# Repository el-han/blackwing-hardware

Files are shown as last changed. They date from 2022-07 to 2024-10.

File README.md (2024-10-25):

# Blackwing keyboard

The Blackwing keyboard is a vertically staggered split keyboard inspired by the [Mitosis keyboard](https://github.com/reversebias/mitosis).

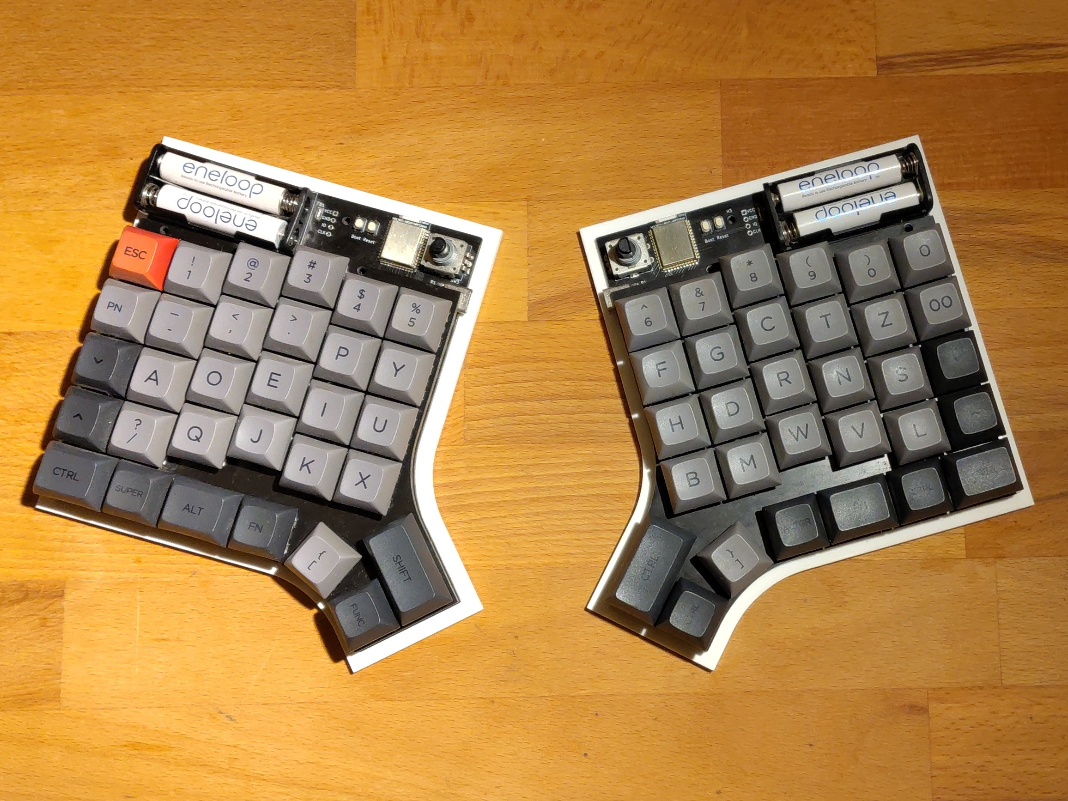
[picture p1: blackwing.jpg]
Don't mind the keycap labels


## Features

- QMK firmware
- Cherry MX switches
- nRF52840 module
- NKRO as each switch is wired to its own GPIO
- Nordic's proprietary low power radio protocol
- Uses the receiver from the [Mitosis keyboard](https://github.com/reversebias/mitosis)
- Runs months to years on battery as it stays in deep sleep until a button is pressed or released
- PCB plate for plate mounted switches

## Todo

- Merge firmware into QMK project
- Use nRF 52840 dongle as receiver
- Build a ZMK based firmware
- Add Bluetooth support

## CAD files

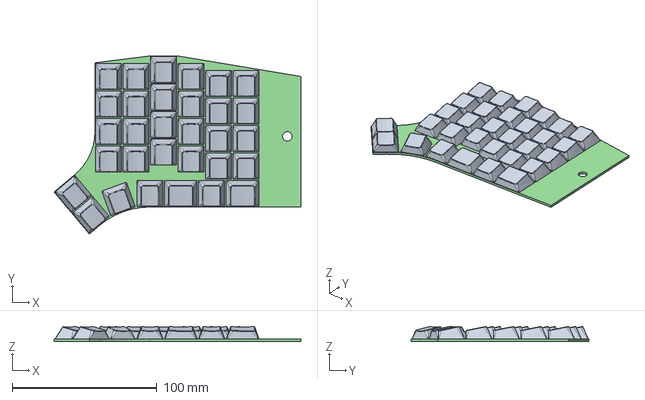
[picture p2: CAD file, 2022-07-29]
plate/plate.step
170.8 x 123.2 x 10.3 mm

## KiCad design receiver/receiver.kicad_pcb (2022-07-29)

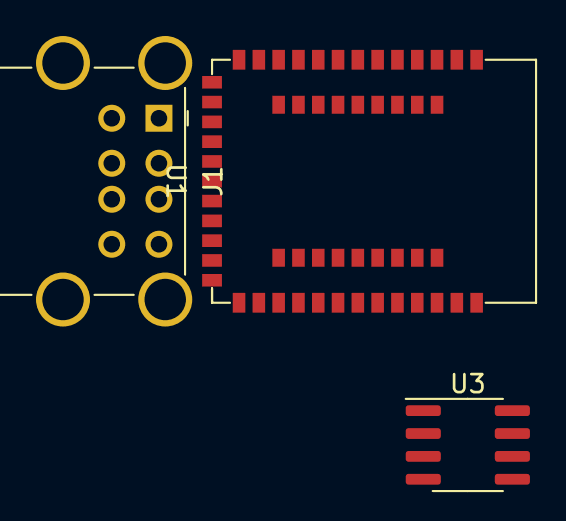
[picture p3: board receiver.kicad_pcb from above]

Board: 2 copper layers, 4 parts (1 on the bottom side), 4 nets, no tracks yet.

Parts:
J1: USB_A; USB_A_Wuerth_61400826021_Horizontal_Stacked
U1: HOLYIOT-18010-NRF52840
U2: ATmega32U4-A; TQFP-44_10x10mm_P0.8mm
U3: AMS1117CS-3.3; SOIC-8_3.9x4.9mm_P1.27mm

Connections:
unnamed: U2.14 (VCC), U2.34 (VCC)
unnamed: U2.15 (GND), U2.23 (GND), U2.35 (GND), U2.43 (GND)
unnamed: U2.24 (AVCC), U2.44 (AVCC)
unnamed: U3.2 (VO), U3.3 (VO), U3.6 (VO), U3.7 (VO)

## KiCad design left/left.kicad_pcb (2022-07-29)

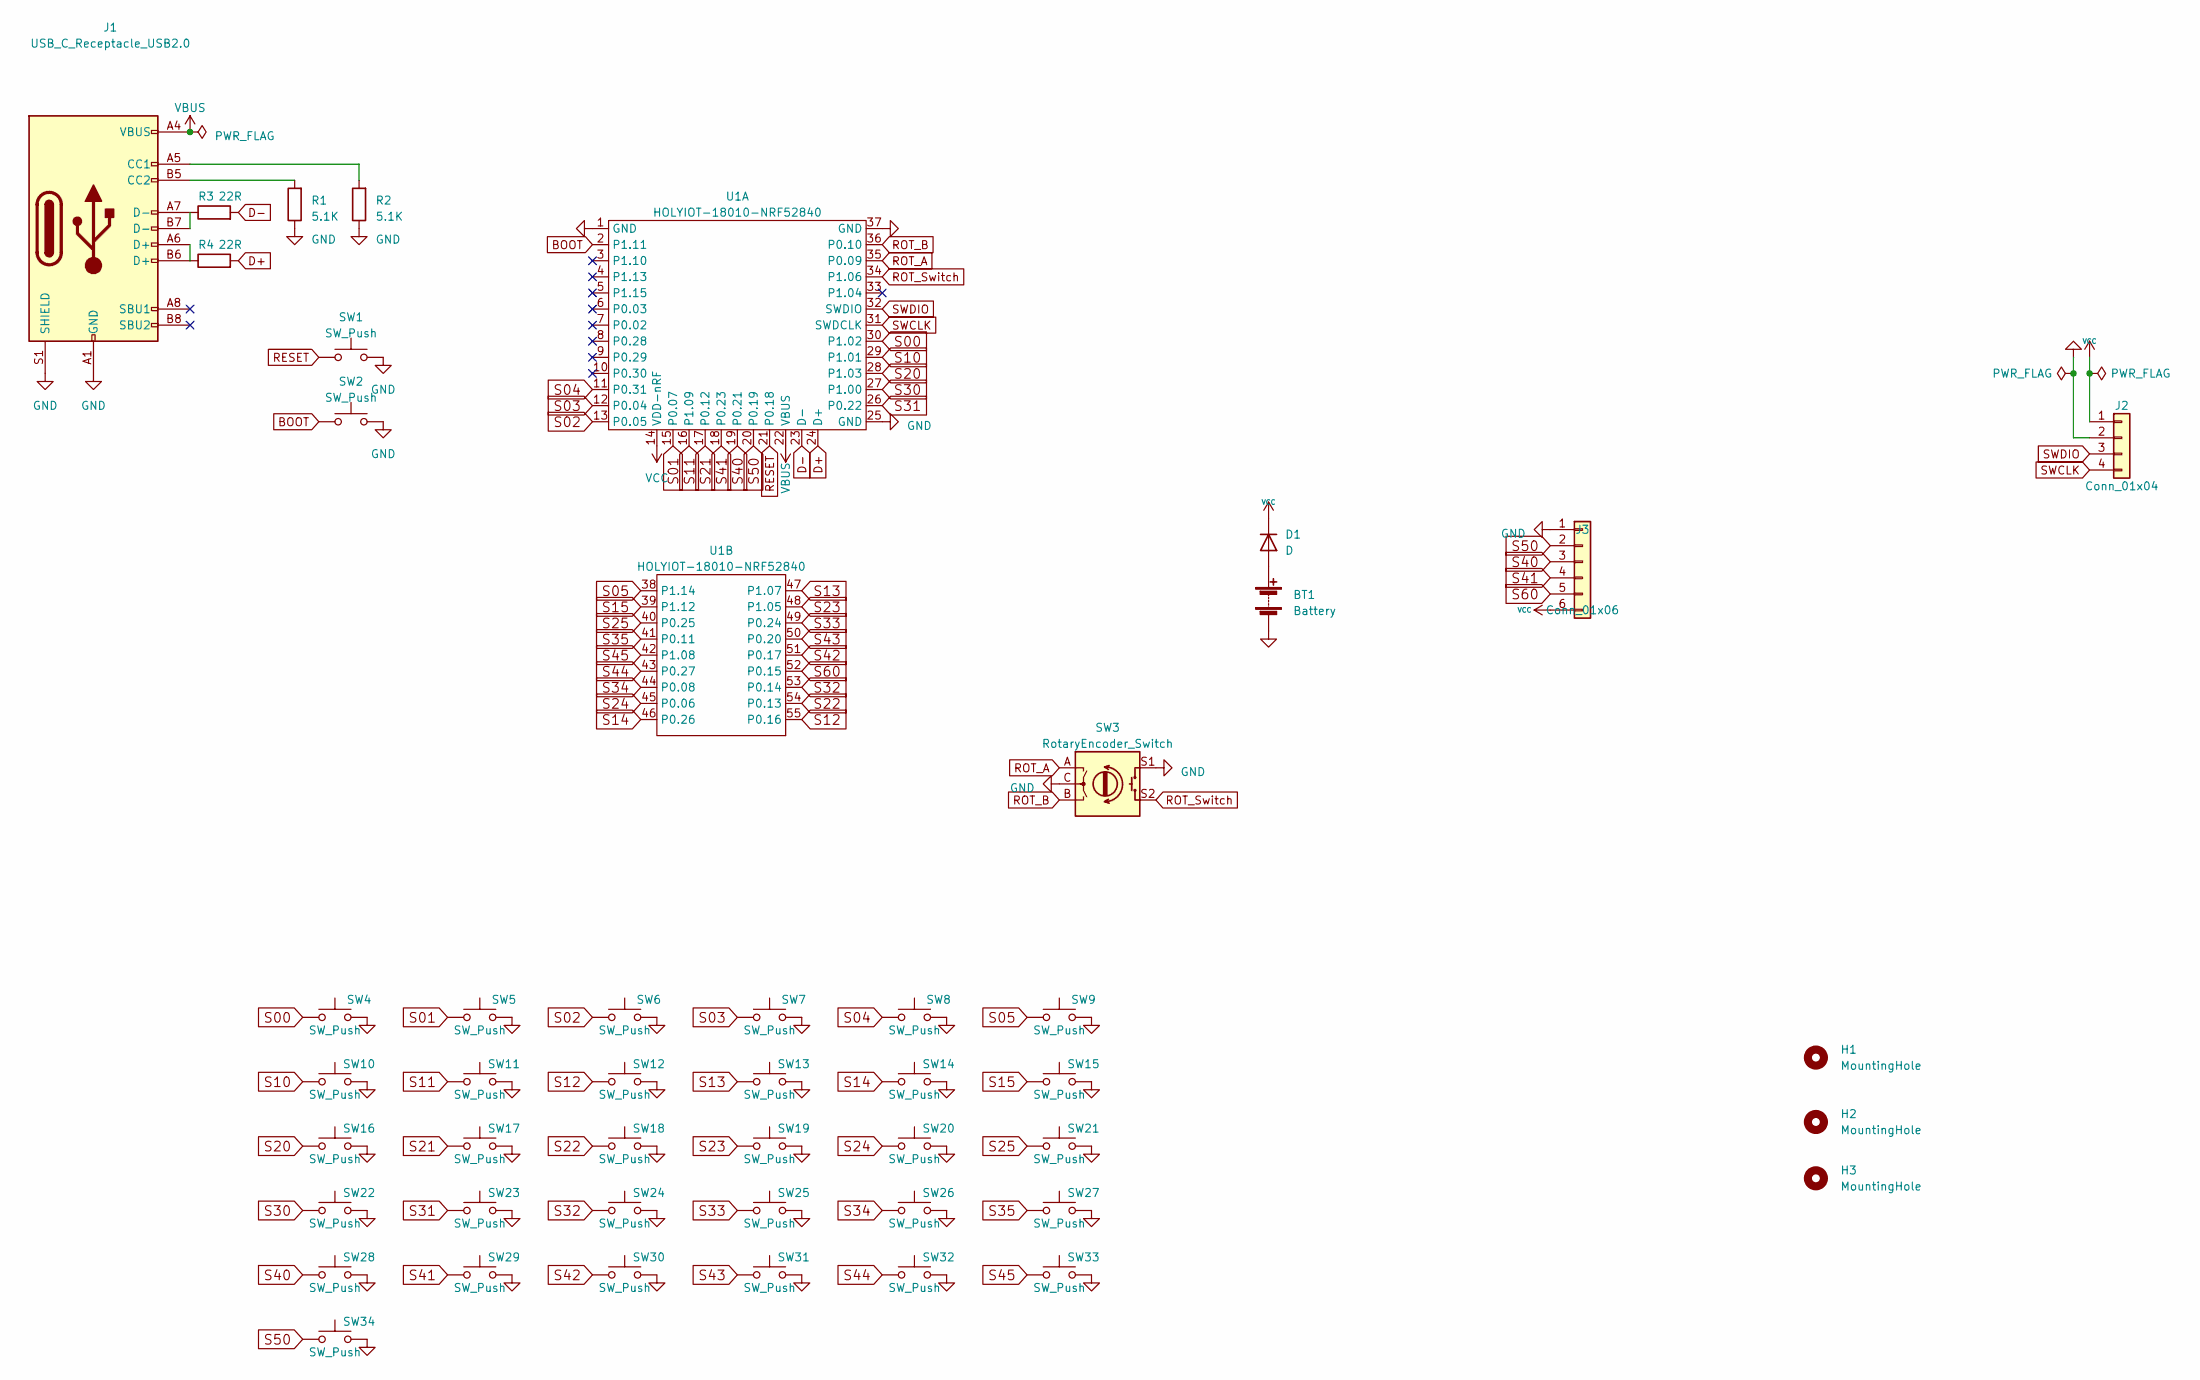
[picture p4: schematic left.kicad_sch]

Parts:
BT1: Battery; BatteryHolder_Keystone_2468_2xAAA
D1: D; D_SOD-123
H1, H2, H3: MountingHole; MountingHole_2.7mm_M2.5_DIN965
J1: USB_C_Receptacle_USB2.0; USB_C_Receptacle_GCT_USB4085
J2: Conn_01x04; Programming_Header
J3: Conn_01x06; PinHeader_1x06_P2.54mm_Vertical
R1, R2: 5.1K; R_0603_1608Metric
R3, R4: 22R; R_0402_1005Metric
SW1, SW2: SW_Push; SW_Push_1P1T_NO_Vertical_Wuerth_434133025816
SW3: RotaryEncoder_Switch; RotaryEncoder_Alps_EC12E-Switch_Vertical_H20mm
SW4, SW5, SW6, SW7, SW8, SW9, SW10, SW11, SW12, SW13, SW14, SW15, SW16, SW17, SW18, SW19, SW20, SW21, SW22, SW23, SW24, SW25, SW26, SW27, SW28, SW29, SW30, SW32: SW_Push; SW_Cherry_MX_1.00u_PCB
SW31, SW33: SW_Push; SW_Cherry_MX_1.25u_PCB
SW34: SW_Push; SW_Cherry_MX_1.75u_PCB
U1: HOLYIOT-18010-NRF52840

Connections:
BOOT: SW2.1, U1.2 (P1.11)
D+: R4.2, U1.24 (D+)
D-: R3.2, U1.23 (D-)
GND: BT1.2 (-), J1.A1 (GND), J1.A12 (GND), J1.B1 (GND), J1.B12 (GND), J1.S1 (SHIELD), J2.2, J3.1, R1.1, R2.1, SW1.2, SW2.2, SW3.C, SW3.S1, SW4.2, SW5.2, SW6.2, SW7.2, SW8.2, SW9.2, SW10.2, SW11.2, SW12.2, SW13.2, SW14.2, SW15.2, SW16.2, SW17.2, SW18.2, SW19.2, SW20.2, SW21.2, SW22.2, SW23.2, SW24.2, SW25.2, SW26.2, SW27.2, SW28.2, SW29.2, SW30.2, SW31.2, SW32.2, SW33.2, SW34.2, U1.1 (GND), U1.25 (GND), U1.37 (GND)
unnamed: BT1.1 (+), D1.2 (A)
unnamed: J1.A5 (CC1), R2.2
unnamed: J1.A6 (D+), J1.B6 (D+), R4.1
unnamed: J1.A7 (D-), J1.B7 (D-), R3.1
unnamed: J1.B5 (CC2), R1.2
RESET: SW1.1, U1.21 (P0.18)
ROT_A: SW3.A, U1.35 (P0.09)
ROT_B: SW3.B, U1.36 (P0.10)
ROT_Switch: SW3.S2, U1.34 (P1.06)
S00: SW4.1, U1.30 (P1.02)
S01: SW5.1, U1.15 (P0.07)
S02: SW6.1, U1.13 (P0.05)
S03: SW7.1, U1.12 (P0.04)
S04: SW8.1, U1.11 (P0.31)
S05: SW9.1, U1.38 (P1.14)
S10: SW10.1, U1.29 (P1.01)
S11: SW11.1, U1.16 (P1.09)
S12: SW12.1, U1.55 (P0.16)
S13: SW13.1, U1.47 (P1.07)
S14: SW14.1, U1.46 (P0.26)
S15: SW15.1, U1.39 (P1.12)
S20: SW16.1, U1.28 (P1.03)
S21: SW17.1, U1.17 (P0.12)
S22: SW18.1, U1.54 (P0.13)
S23: SW19.1, U1.48 (P1.05)
S24: SW20.1, U1.45 (P0.06)
S25: SW21.1, U1.40 (P0.25)
S30: SW22.1, U1.27 (P1.00)
S31: SW23.1, U1.26 (P0.22)
S32: SW24.1, U1.53 (P0.14)
S33: SW25.1, U1.49 (P0.24)
S34: SW26.1, U1.44 (P0.08)
S35: SW27.1, U1.41 (P0.11)
S40: J3.3, SW28.1, U1.19 (P0.21)
S41: J3.4, SW29.1, U1.18 (P0.23)
S42: SW30.1, U1.51 (P0.17)
S43: SW31.1, U1.50 (P0.20)
S44: SW32.1, U1.43 (P0.27)
S45: SW33.1, U1.42 (P1.08)
S50: J3.2, SW34.1, U1.20 (P0.19)
S60: J3.5, U1.52 (P0.15)
SWCLK: J2.4, U1.31 (SWDCLK)
SWDIO: J2.3, U1.32 (SWDIO)
VBUS: J1.A4 (VBUS), J1.A9 (VBUS), J1.B4 (VBUS), J1.B9 (VBUS), U1.22 (VBUS)
VCC: D1.1 (K), J2.1, J3.6, U1.14 (VDD-nRF)

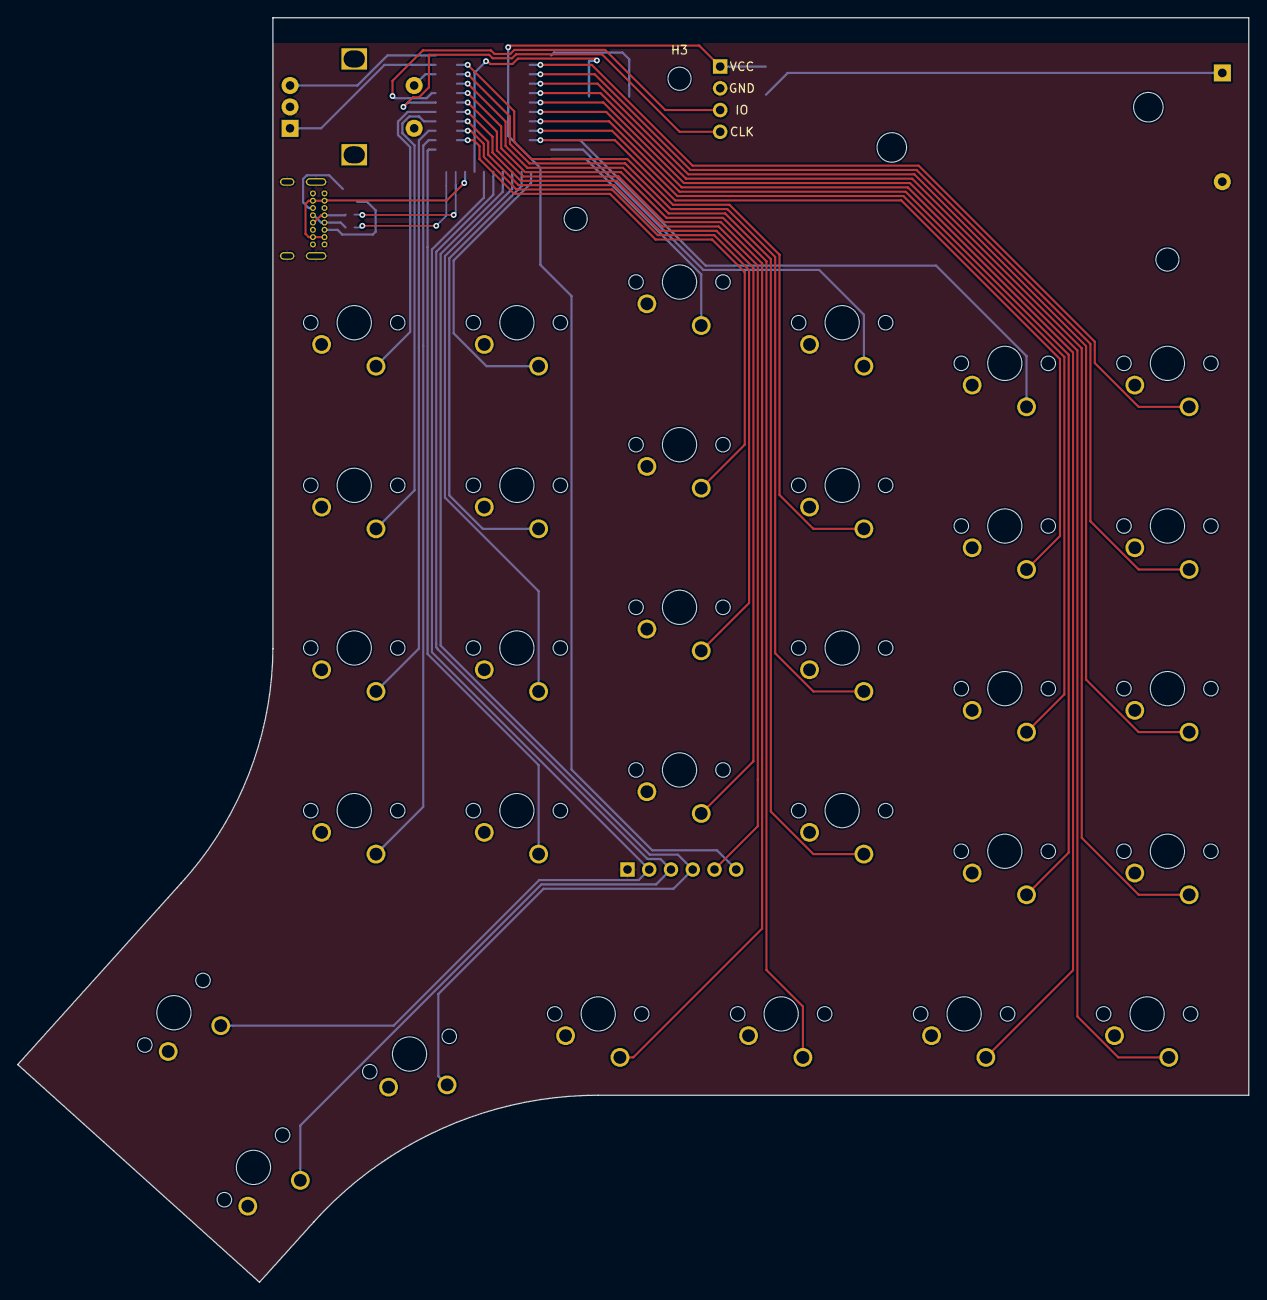
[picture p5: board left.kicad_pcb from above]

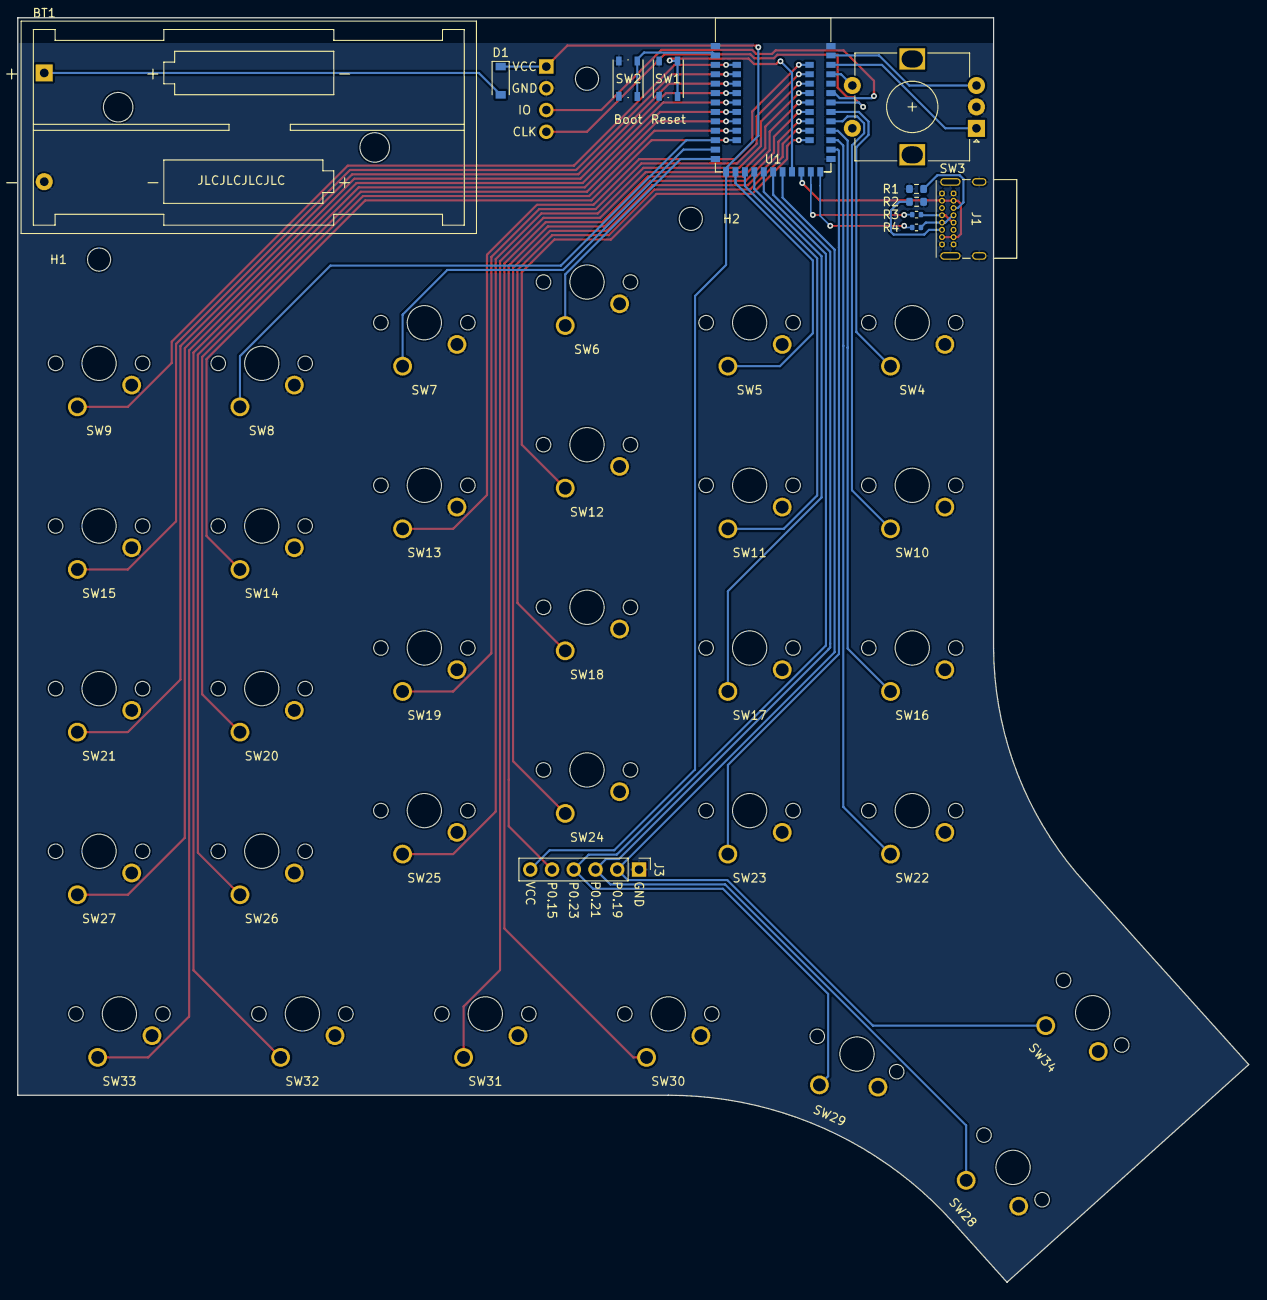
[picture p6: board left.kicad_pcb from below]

Board: 2 copper layers, 143.8 x 147.7 mm, 47 parts (46 on the bottom side), 49 nets.

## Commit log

2018-05-02 vertically staggered design
    [blackwing.kicad_pcb, blackwing.sch]
2018-08-08 convert to kicad 5.0
    [blackwing.kicad_pcb, blackwing.sch]
2018-09-17 version 2
    [blackwing.kicad_pcb, blackwing.sch]
2018-09-17 v 2.1
    [blackwing.kicad_pcb]
2018-09-18 make outline smaller
    [blackwing.kicad_pcb]
2018-10-06 move key columns
    [blackwing.kicad_pcb, blackwing.sch]
2021-07-15 redesign, batteries on the outer edge
    [blackwing-B_Cu.gbl, blackwing-B_Cu.gbr, blackwing-B_Mask.gbr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]
2021-07-17 right finished, left wip
    [blackwing.kicad_pcb, blackwing.kicad_sch, left.brd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]
2021-07-18 finish left
    [blackwing-B_Cu.gbl, blackwing-B_Cu.gbr, blackwing-B_Mask.gbr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]
2021-07-18 move footprint library to commen directory
    [left.kicad_pcb, right.kicad_pcb]
2021-07-18 add all system footprint libraries
2021-07-20 update footprint of rf module
    [left.kicad_pcb, left.kicad_sch, plate.kicad_pcb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]
2021-07-20 minor fixes
    [right.kicad_pcb]
2022-07-29 add receiver and update file versions
    [receiver.kicad_pcb, receiver.kicad_sch]
